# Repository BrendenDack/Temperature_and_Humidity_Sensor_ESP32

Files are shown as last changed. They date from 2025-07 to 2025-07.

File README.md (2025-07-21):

# Temperature and Humidity Sensor using an ESP32

This project uses an esp32doit-devkit-v1 board, a DHT11 temperature and humidity sensor, and a LCD1602 16x2 LCD screen to display the sensor readings for the user.
The board also has a button for toggling between Farenheit and Celsius, and it hosts an internal HTTP server to displaying the readings on a local website.
There is an onboard Potentiometer that can be used to adjust the screen contrast, if you want to use a static resistor instead, I find around 8.2Kohm works best.

This project was developed in the Arduino IDE, and later imported into PlatformIO.

To get started with this project: 

## Hardware Setup

The circuit:
 * USB to ESP32 Dev Board
 * LCD RS pin to digital pin 32
 * LCD Enable pin to digital pin 33
 * LCD D4 pin to digital pin 25
 * LCD D5 pin to digital pin 26
 * LCD D6 pin to digital pin 27
 * LCD D7 pin to digital pin 14
 * LCD R/W pin to ground
 * LCD VSS pin to ground
 * LCD VCC pin to 5V
 * 10K potentiometer:
 * ends to +5V and ground
 * wiper to LCD VO pin (pin 3)
 * DHT11 VCC to 5V
 * DHT11 GND to GND
 * DHT11 DATA to pin 13
 * Button to pin 34 (REQUIRES 3.3V, 5V will not work)
 * 10Kohm pulldown resistor for button to ground

Here is a picture of the physical design on a breadboard. I have a power supply on one end that is only used to jump 5V to both power rails and the same effect can be had using jumper wires.
The Dev board has an onboard voltage regulator that accepts 5V, and has a 3.3V output that you can use to wire up the button. This way you do not have to supply both 5V and 3.3V manually.
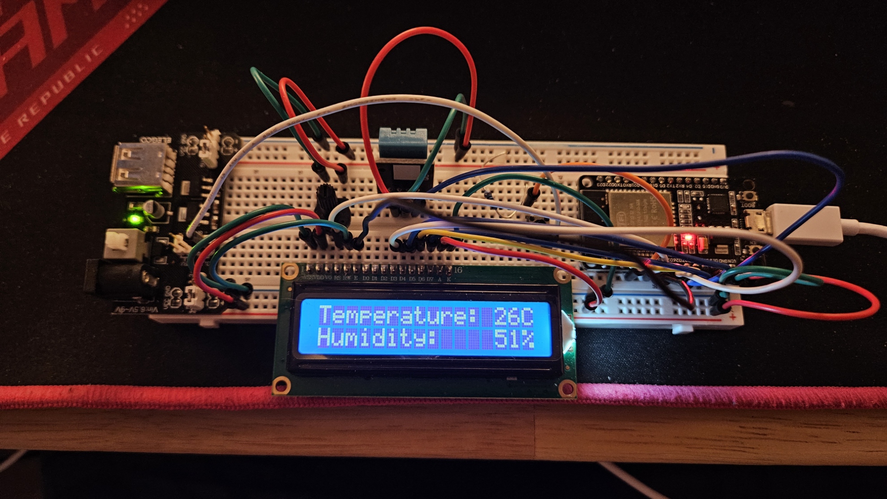
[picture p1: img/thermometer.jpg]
Image of board


Here is a picture of the website. It is made using very basic html, css, and js.
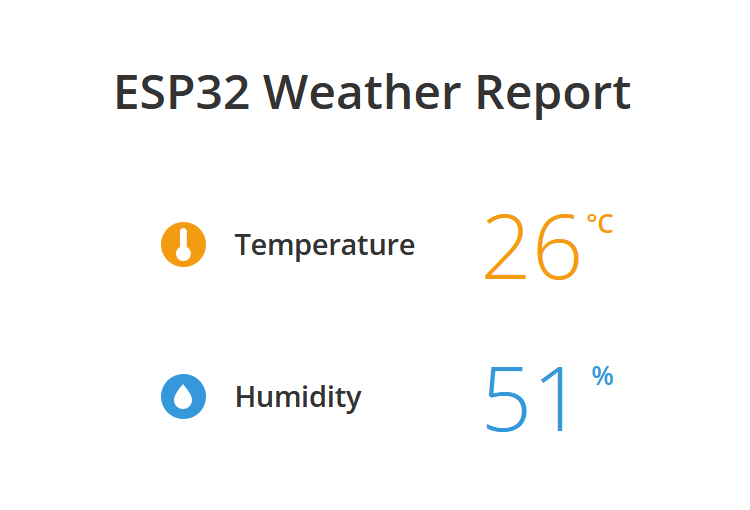
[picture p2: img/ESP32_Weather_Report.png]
Image of website


Inside /kicad_files contains the kicad schematic and pcb files. You can reference these for how the pcb is assembled, however the gpio connections in the schematic are not the same
as the connections defined in the code. This is because I changed the gpio pins for easier traces on the PCB design. If you're planning to build on a breadboard, use the pins defined in the code.

## Software Setup
Clone the repository into a working folder of your choosing.
Then open the project with PlatformIO. Verify that it compiles, then upload it to the ESP32 Dev Board.

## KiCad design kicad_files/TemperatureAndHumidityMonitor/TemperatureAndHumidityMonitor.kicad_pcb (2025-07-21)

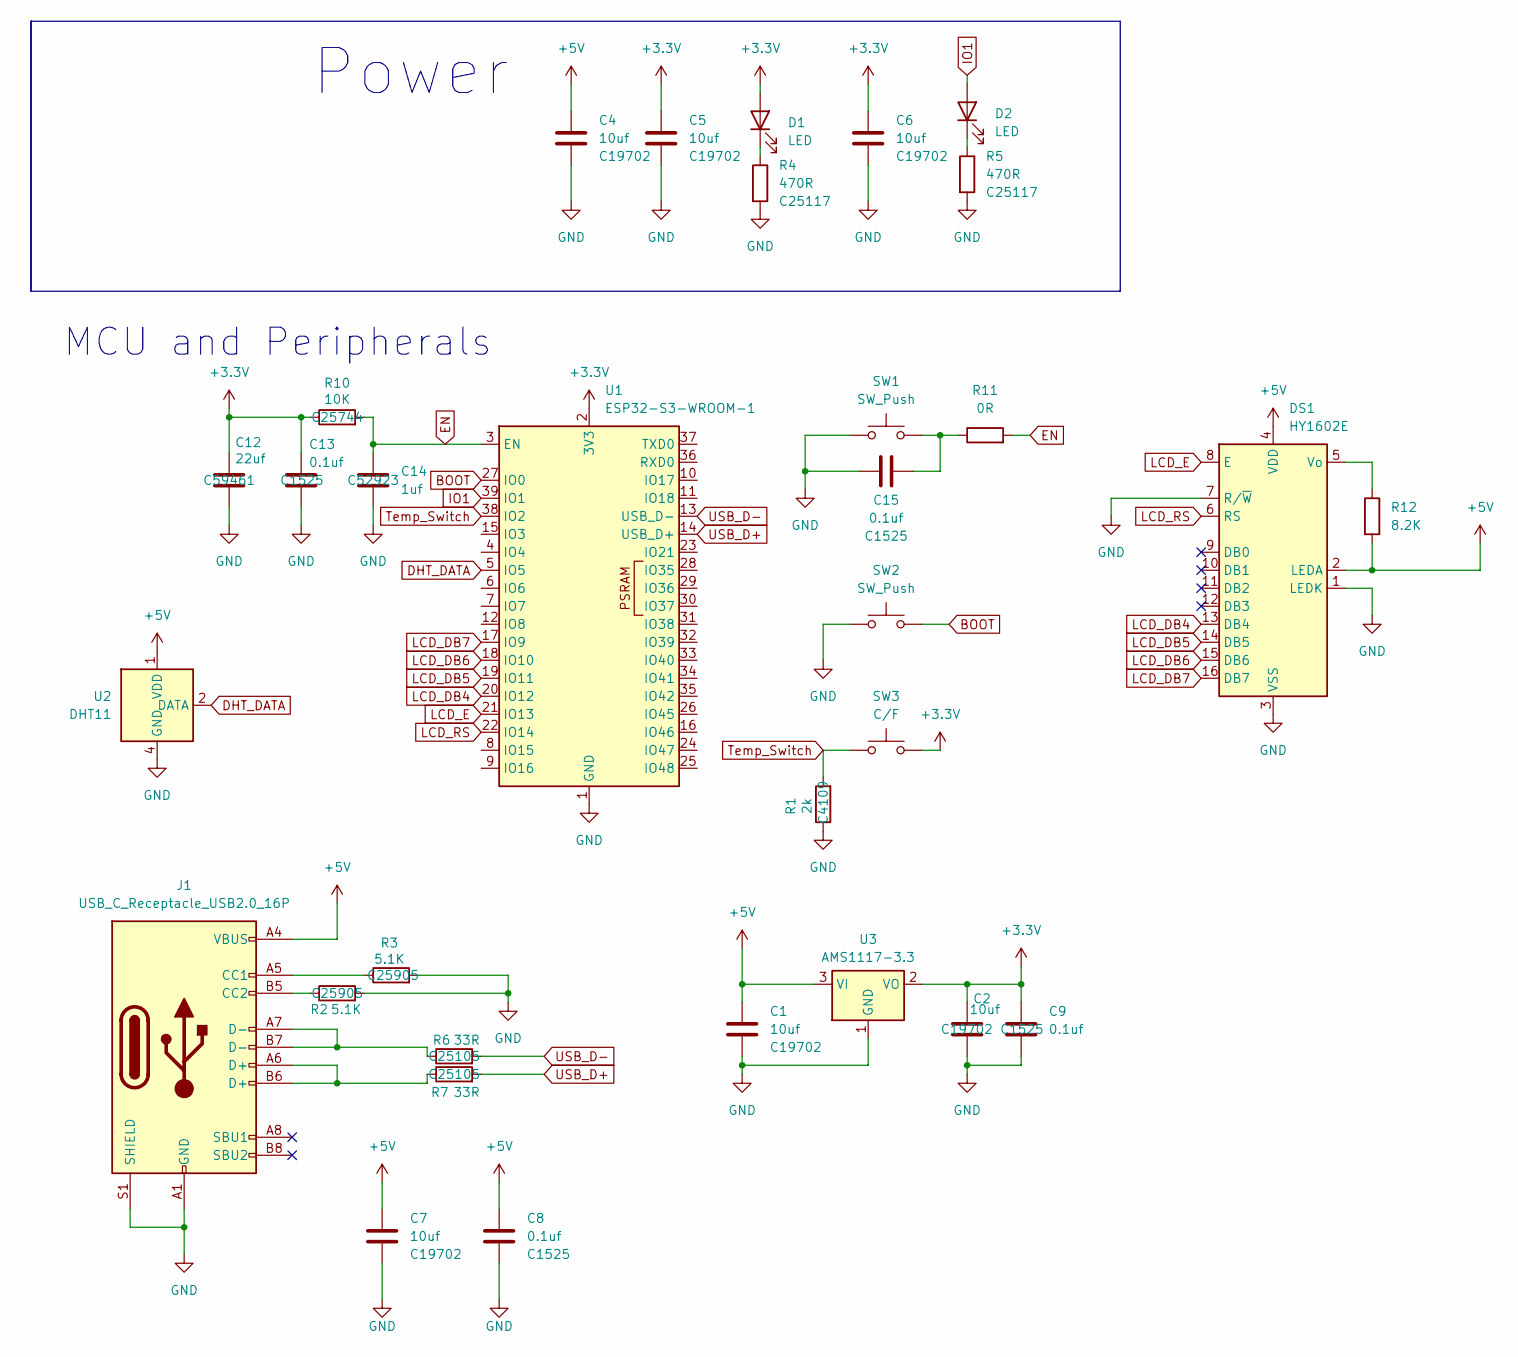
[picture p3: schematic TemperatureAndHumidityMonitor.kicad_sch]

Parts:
C1, C2, C4, C5, C6, C7: 10uf; C_0201_0603Metric; MNF PART NUMBER C19702
C8, C9, C13, C15: 0.1uf; C_0402_1005Metric; MNF PART NUMBER C1525
C12: 22uf; C_0201_0603Metric; MNF PART NUMBER C59461
C14: 1uf; C_0402_1005Metric; MNF PART NUMBER C52923
D1, D2: LED; LED_0201_0603Metric; MNF PART NUMBER C2286
DS1: HY1602E
J1: USB_C_Receptacle_USB2.0_16P; USB_C_Receptacle_G-Switch_GT-USB-7010ASV; MNF PART NUMBER C2988369
R1: 2k; R_0402_1005Metric; MNF PART NUMBER C4109
R2, R3: 5.1K; R_0402_1005Metric; MNF PART NUMBER C25905
R4, R5: 470R; R_0402_1005Metric; MNF PART NUMBER C25117
R6, R7: 33R; R_0402_1005Metric; MNF PART NUMBER C25105
R10: 10K; R_0402_1005Metric; MNF PART NUMBER C25744
R11: 0R; R_0402_1005Metric; MNF PART NUMBER C17168
R12: 8.2K; R_0201_0603Metric; MNF PART NUMBER C25981
SW1, SW2: SW_Push; SW_SPST_B3U-1000P; MNF PART NUMBER C720477
SW3: C/F; SW_SPST_B3U-1000P; MNF PART NUMBER C720477
U1: ESP32-S3-WROOM-1; MNF PART NUMBER C2913197
U2: DHT11; Aosong_DHT11_5.5x12.0_P2.54mm; MNF PART NUMBER C117051
U3: AMS1117-3.3; SOT-223-3_TabPin2; MNF PART NUMBER C6186

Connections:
+3.3V: C2.1, C5.1, C6.1, C9.1, C12.1, C13.1, D1.2 (A), R10.1, SW3.2, U1.2 (3V3), U3.2 (VO)
+5V: C1.1, C4.1, C7.1, C8.1, DS1.2 (LEDA), DS1.4 (VDD), J1.A4 (VBUS), J1.A9 (VBUS), J1.B4 (VBUS), J1.B9 (VBUS), R12.2, U2.1 (VDD), U3.3 (VI)
BOOT: SW2.2, U1.27 (IO0)
DHT_DATA: U1.5 (IO5), U2.2 (DATA)
EN: C14.1, R10.2, R11.2, U1.3 (EN)
GND: C1.2, C2.2, C4.2, C5.2, C6.2, C7.2, C8.2, C9.2, C12.2, C13.2, C14.2, C15.1, DS1.1 (LEDK), DS1.3 (VSS), DS1.7 (R/~W), J1.A1 (GND), J1.A12 (GND), J1.B1 (GND), J1.B12 (GND), J1.S1 (SHIELD), R1.1, R2.2, R3.2, R4.2, R5.2, SW1.1, SW2.1, U1.1 (GND), U1.40 (GND), U1.41 (GND), U2.4 (GND), U3.1 (GND)
IO1: D2.2 (A), U1.39 (IO1)
LCD_DB4: DS1.13 (DB4), U1.20 (IO12)
LCD_DB5: DS1.14 (DB5), U1.19 (IO11)
LCD_DB6: DS1.15 (DB6), U1.18 (IO10)
LCD_DB7: DS1.16 (DB7), U1.17 (IO9)
LCD_E: DS1.8 (E), U1.21 (IO13)
LCD_RS: DS1.6 (RS), U1.22 (IO14)
unnamed: C15.2, R11.1, SW1.2
unnamed: D1.1 (K), R4.1
unnamed: D2.1 (K), R5.1
unnamed: DS1.5 (Vo), R12.1
unnamed: J1.A5 (CC1), R3.1
unnamed: J1.B5 (CC2), R2.1
unnamed: J1.A6 (D+), J1.B6 (D+), R7.1
unnamed: J1.A7 (D-), J1.B7 (D-), R6.1
Temp_Switch: R1.2, SW3.1, U1.38 (IO2)
USB_D+: R7.2, U1.14 (USB_D+)
USB_D-: R6.2, U1.13 (USB_D-)

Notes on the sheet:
Power
MCU and Peripherals

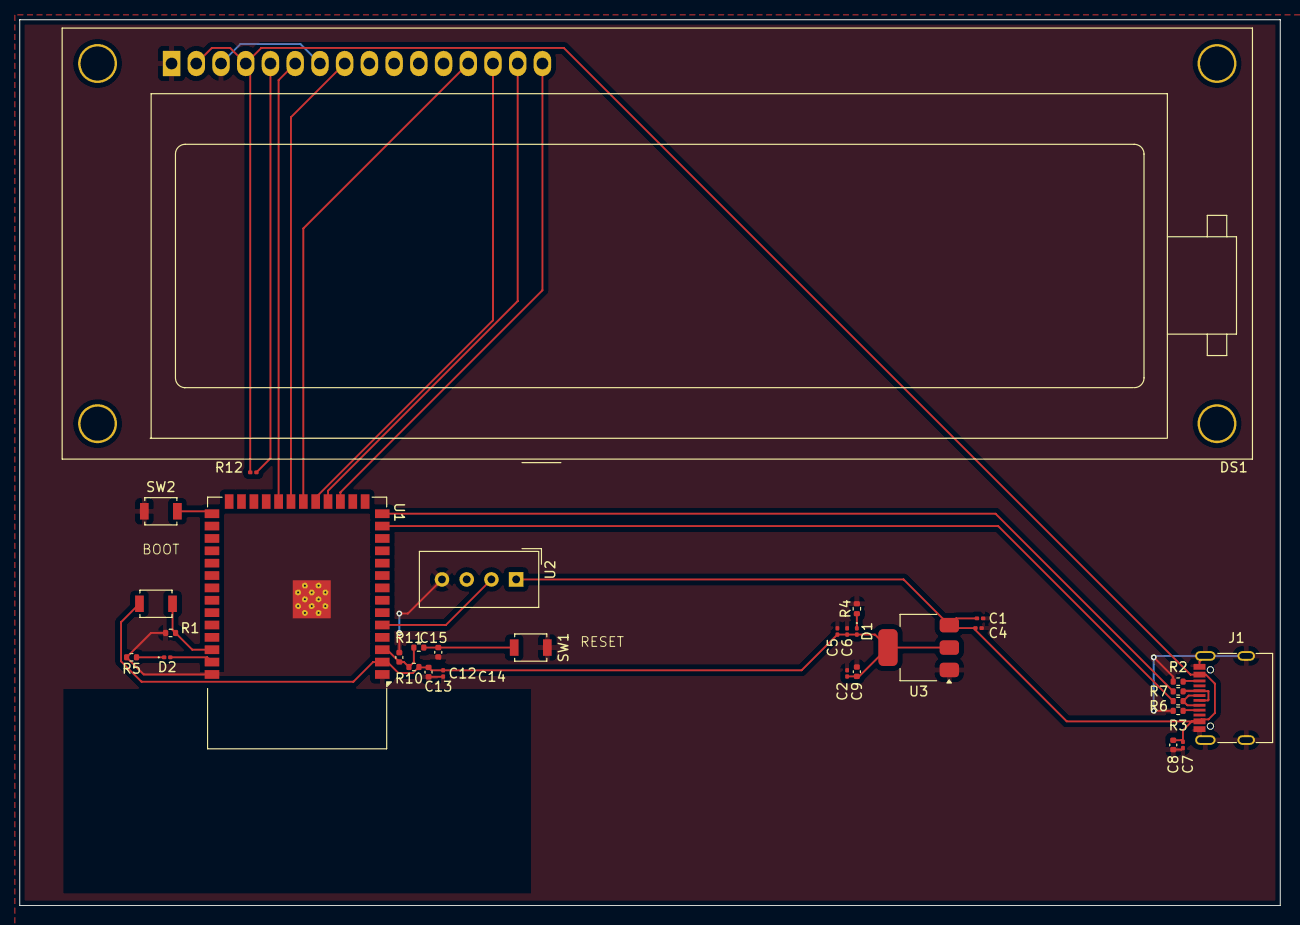
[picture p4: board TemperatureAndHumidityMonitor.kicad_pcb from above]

Board: 2 copper layers, 129.5 x 91.0 mm, 32 parts (0 on the bottom side), 24 nets.

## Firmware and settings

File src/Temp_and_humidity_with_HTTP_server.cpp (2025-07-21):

// Brenden Dack
// 07/04/2025

/*
  LiquidCrystal Library/DHT11 Temperature and Humidity module Library - Thermometer

 This sketch reads the temperature and humidity from the DHT11 module
 then writes the output to the LCD1602 module

  The circuit:
 * LCD RS pin to digital pin 32
 * LCD Enable pin to digital pin 33
 * LCD D4 pin to digital pin 25
 * LCD D5 pin to digital pin 26
 * LCD D6 pin to digital pin 27
 * LCD D7 pin to digital pin 14
 * LCD R/W pin to ground
 * LCD VSS pin to ground
 * LCD VCC pin to 5V
 * 10K resistor:
 * ends to +5V and ground
 * wiper to LCD VO pin (pin 3)
 * DHT11 VCC to 5V
 * DHT11 GND to GND
 * DHT11 DATA to pin 13
 * Button to pin 34
*/
// include the library code:
#include <Arduino.h>
#include <LiquidCrystal.h>
#include <DHT11.h>
#include <WiFi.h>
#include <WebServer.h>
#include <secret_keys.h>

// Function Declarations
void handle_OnConnect();
void handle_NotFound();
String SendHTML(int TempCstat, int Humiditystat);

// initialize the library with the numbers of the interface pins
LiquidCrystal lcd(32, 33, 25, 26, 27, 14);
// initialize the library with the data pin number
DHT11 dht11(13);
// initialize the web server
WebServer server(80);
// initialize button for F/C swapping
int ButtonPin = 34;
// bool to track if displaying Fahrenheit or Celsius
bool tempMode = false;

// variables for holding temperature and humidity values
int temperature = 0;
int humidity = 0;

/* WiFi SSID & Password are in secret_keys.hpp*/

void setup() {
  // set up the LCD's number of columns and rows:
  lcd.begin(16, 2);
  // set DHT11 delay between sensor reading to give LCD time to display (4 seconds)
  dht11.setDelay(500);
  // set pinMode for button
  pinMode(ButtonPin, INPUT);
  // Debug Serial connection
  //Serial.begin(9600);
  Serial.begin(115200);

  Serial.println("Connecting to ");
  Serial.println(ssid);
  lcd.clear();
  lcd.setCursor(0, 0);
  lcd.print("Connecting to ");
  lcd.setCursor(0, 1);
  lcd.print(ssid);
  // Connect to local WiFi
  WiFi.begin(ssid, password);

  // check WiFi is connected to network
  while (WiFi.status() != WL_CONNECTED) {
    delay(1000);
    Serial.print(".");
  }
  Serial.println("");
  Serial.println("WiFi connected..!");
  Serial.print("Got IP: ");
  Serial.println(WiFi.localIP());

  server.on("/", handle_OnConnect);
  server.onNotFound(handle_NotFound);

  server.begin();
  Serial.println("HTTP Server Started");
  
  delay(3000);
  lcd.clear();
  lcd.setCursor(0, 0);
  lcd.println("WiFi connected!");
  lcd.setCursor(0, 1);
  lcd.print("-> ");
  lcd.print(WiFi.localIP());
  delay(5000);
}

void loop() {
  // function to handle when client makes request to HTTP server
  server.handleClient();
  
  // set the cursor to column 0, line 1
  // (note: line 1 is the second row, since counting begins with 0):
  //lcd.clear();
  lcd.setCursor(0, 0);
  
  // print the number of seconds since reset:
  //lcd.print(millis() / 1000);
  int result = dht11.readTemperatureHumidity(temperature, humidity);

  // Swap temp display when button is pressed
  if (digitalRead(ButtonPin) == HIGH) {
    tempMode = !tempMode;
  }

  if (result == 0) {
    // print temperature to LCD
    lcd.print("Temperature: ");
    // temp set to Celsius
    if (tempMode == false) {
      lcd.print(temperature);
      lcd.print("C");
    }
    else if (tempMode == true) {
      // convert from Celsius to Fahrenheit
      int temp = ((temperature * 9)/5) + 32;
      lcd.print(temp);
      lcd.print("F");
    }
    
    // move cursor to second line
    lcd.setCursor(0, 1);
    // print humidity to LCD
    lcd.print("Humidity:    ");
    lcd.print(humidity);
    lcd.print("%");
    
    /* Debug prints
    Serial.print( "T = " );
    Serial.print( temperature, 1 );
    Serial.print( " deg. C, H = " );
    Serial.print( humidity, 1 );
    Serial.println( "%" );
    Serial.print("Temp mode: ");
    Serial.println(tempMode);
    */
  }
  else {
    lcd.println(DHT11::getErrorString(result));
  }
}

void handle_OnConnect() {
  server.send(200, "text/html", SendHTML(temperature, humidity));
}
void handle_NotFound() {
  server.send(404, "text/plain", "Not Found");
}

String SendHTML(int TempCstat, int Humiditystat){
  String ptr = "<!DOCTYPE html> <html>\n";
  ptr +="<head><meta name=\"viewport\" content=\"width=device-width, initial-scale=1.0, user-scalable=no\">\n";
  ptr +="<link href=\"https://fonts.googleapis.com/css?family=Open+Sans:300,400,600\" rel=\"stylesheet\">\n";
  ptr +="<title>ESP32 Weather Report</title>\n";
  ptr +="<style>html { font-family: 'Open Sans', sans-serif; display: block; margin: 0px auto; text-align: center;color: #333333;}\n";
  ptr +="body{margin-top: 50px;}\n";
  ptr +="h1 {margin: 50px auto 30px;}\n";
  ptr +=".side-by-side{display: inline-block;vertical-align: middle;position: relative;}\n";
  ptr +=".humidity-icon{background-color: #3498db;width: 30px;height: 30px;border-radius: 50%;line-height: 36px;}\n";
  ptr +=".humidity-text{font-weight: 600;padding-left: 15px;font-size: 19px;width: 160px;text-align: left;}\n";
  ptr +=".humidity{font-weight: 300;font-size: 60px;color: #3498db;}\n";
  ptr +=".temperature-icon{background-color: #f39c12;width: 30px;height: 30px;border-radius: 50%;line-height: 40px;}\n";
  ptr +=".temperature-text{font-weight: 600;padding-left: 15px;font-size: 19px;width: 160px;text-align: left;}\n";
  ptr +=".temperature{font-weight: 300;font-size: 60px;color: #f39c12;}\n";
  ptr +=".superscript{font-size: 17px;font-weight: 600;position: absolute;right: -20px;top: 15px;}\n";
  ptr +=".data{padding: 10px;}\n";
  ptr +="</style>\n";
  ptr +="<script>\n";
  ptr +="setInterval(loadDoc,200);\n";
  ptr +="function loadDoc() {\n";
  ptr +="var xhttp = new XMLHttpRequest();\n";
  ptr +="xhttp.onreadystatechange = function() {\n";
  ptr +="if (this.readyState == 4 && this.status == 200) {\n";
  ptr +="document.getElementById(\"webpage\").innerHTML =this.responseText}\n";
  ptr +="};\n";
  ptr +="xhttp.open(\"GET\", \"/\", true);\n";
  ptr +="xhttp.send();\n";
  ptr +="}\n";
  ptr +="</script>\n";
  ptr +="</head>\n";
  ptr +="<body>\n";
  
   ptr +="<div id=\"webpage\">\n";
   
   ptr +="<h1>ESP32 Weather Report</h1>\n";
   ptr +="<div class=\"data\">\n";
   ptr +="<div class=\"side-by-side temperature-icon\">\n";
   ptr +="<svg version=\"1.1\" id=\"Layer_1\" xmlns=\"http://www.w3.org/2000/svg\" xmlns:xlink=\"http://www.w3.org/1999/xlink\" x=\"0px\" y=\"0px\"\n";
   ptr +="width=\"9.915px\" height=\"22px\" viewBox=\"0 0 9.915 22\" enable-background=\"new 0 0 9.915 22\" xml:space=\"preserve\">\n";
   ptr +="<path fill=\"#FFFFFF\" d=\"M3.498,0.53c0.377-0.331,0.877-0.501,1.374-0.527C5.697-0.04,6.522,0.421,6.924,1.142\n";
   ptr +="c0.237,0.399,0.315,0.871,0.311,1.33C7.229,5.856,7.245,9.24,7.227,12.625c1.019,0.539,1.855,1.424,2.301,2.491\n";
   ptr +="c0.491,1.163,0.518,2.514,0.062,3.693c-0.414,1.102-1.24,2.038-2.276,2.594c-1.056,0.583-2.331,0.743-3.501,0.463\n";
   ptr +="c-1.417-0.323-2.659-1.314-3.3-2.617C0.014,18.26-0.115,17.104,0.1,16.022c0.296-1.443,1.274-2.717,2.58-3.394\n";
   ptr +="c0.013-3.44,0-6.881,0.007-10.322C2.674,1.634,2.974,0.955,3.498,0.53z\"/>\n";
   ptr +="</svg>\n";
   ptr +="</div>\n";
   ptr +="<div class=\"side-by-side temperature-text\">Temperature</div>\n";
   ptr +="<div class=\"side-by-side temperature\">";
   if (tempMode == true) {
    int temp = ((TempCstat * 9)/5) + 32;
    ptr += temp;
    ptr +="<span class=\"superscript\">°F</span></div>\n";
   }
   else {
    ptr +=TempCstat;
    ptr +="<span class=\"superscript\">°C</span></div>\n";
   }
  
   ptr +="</div>\n";
   ptr +="<div class=\"data\">\n";
   ptr +="<div class=\"side-by-side humidity-icon\">\n";
   ptr +="<svg version=\"1.1\" id=\"Layer_2\" xmlns=\"http://www.w3.org/2000/svg\" xmlns:xlink=\"http://www.w3.org/1999/xlink\" x=\"0px\" y=\"0px\"\n\"; width=\"12px\" height=\"17.955px\" viewBox=\"0 0 13 17.955\" enable-background=\"new 0 0 13 17.955\" xml:space=\"preserve\">\n";
   ptr +="<path fill=\"#FFFFFF\" d=\"M1.819,6.217C3.139,4.064,6.5,0,6.5,0s3.363,4.064,4.681,6.217c1.793,2.926,2.133,5.05,1.571,7.057\n";
   ptr +="c-0.438,1.574-2.264,4.681-6.252,4.681c-3.988,0-5.813-3.107-6.252-4.681C-0.313,11.267,0.026,9.143,1.819,6.217\"></path>\n";
   ptr +="</svg>\n";
   ptr +="</div>\n";
   ptr +="<div class=\"side-by-side humidity-text\">Humidity</div>\n";
   ptr +="<div class=\"side-by-side humidity\">";
   ptr +=Humiditystat;
   ptr +="<span class=\"superscript\">%</span></div>\n";
   ptr +="</div>\n";

  ptr +="</div>\n";
  ptr +="</body>\n";
  ptr +="</html>\n";
  return ptr;
}

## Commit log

2025-07-21 changed platformio.ini to use only libraries in lib instead of external libraries from the arduino IDE
2025-07-21 Added readme with instructions and basic summary
    [TemperatureAndHumidityMonitor.kicad_pcb, TemperatureAndHumidityMonitor.kicad_sch]
2025-07-21 Added code to make temp type (C or F) choice reflect on the website as well. Also added variable to platformio.ini to set the correct serial monitor rate.
    [Temp_and_humidity_with_HTTP_server.cpp]
